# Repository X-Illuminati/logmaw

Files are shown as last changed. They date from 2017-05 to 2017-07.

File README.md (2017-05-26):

# logmaw
3D printable vice jaws to convert a "4 in." drill press vice into a makeshift stickvice for electronics workholding.

This is basically an exercise in learning OpenSCAD for me.

The part I've modeled is a set of vice jaws for a relatively generic 4 inch drill press vice.
In this case, I got the vice from [Harbor Freight](https://www.harborfreight.com/4-inch-jaw-capacity-drill-press-vise-30999.html).

In order to use the vice for electronics workholding (soldering, etc.), I have added a simple slot to the design.
Additionally, I have made most of the design parametric, which turned out to be useful since the screw-holes
in the existing vice jaws were clearly drilled with no regard for symmetric placement.

The main STL is [vice_jaws.stl](vice_jaws.stl), but anyone seeking to print these will
probably want to modify the .scad files to match their own vice.

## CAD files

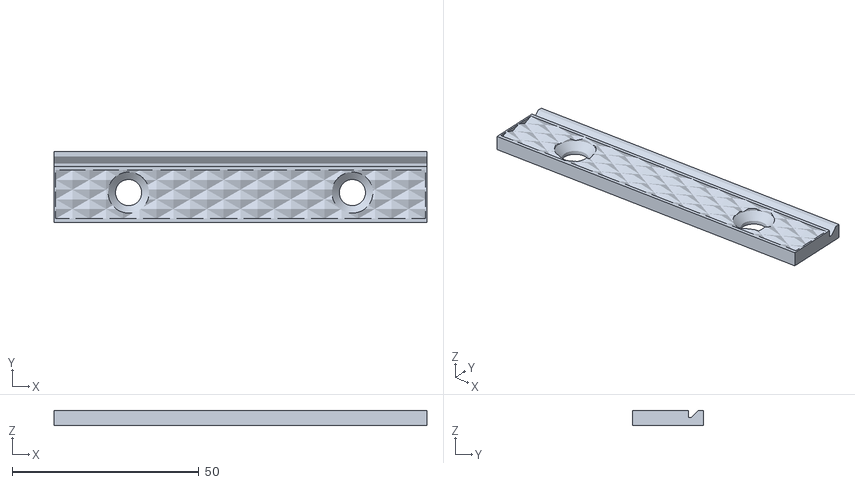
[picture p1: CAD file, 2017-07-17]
vice_jaws.stl
100.0 x 19.0 x 4.00

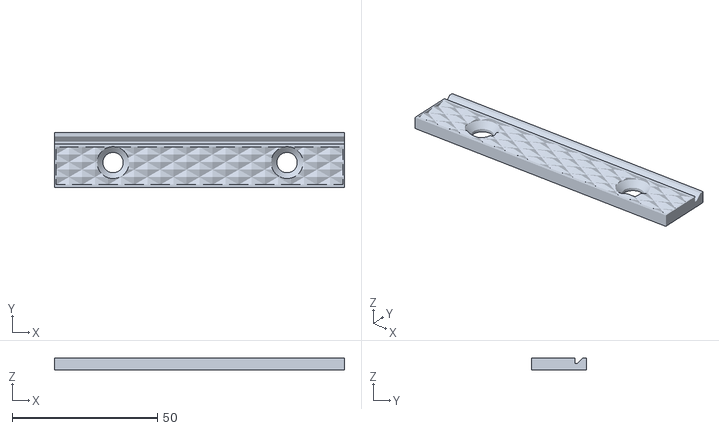
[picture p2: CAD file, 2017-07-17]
371291630_dynamic.stl
100.0 x 19.0 x 4.00

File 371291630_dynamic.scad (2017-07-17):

/*
 * includes
 */
include <vice_jaws.scad>

/*
 * custom settings for vice_jaws.scad
 */
generate_example=false;
bolt_x_offset=0.2;
bolt_y_offset=-0.9;
bolt_distance=60;

/*
 * global defines
 */
label_text1="371291630";
label_text2="dynamic jaw";
label_size=5.5;
label_depth=0.3;

/*
 * main construction geometry
 */
difference() {
	vice_jaw();
	translate([jaw_length/2,jaw_width/2,0])
		rotate([0,180,0])
			linear_extrude(height=(label_depth*2), center=true) {
				translate([0,jaw_width/5,0])
					text(text=label_text1, size=label_size,
						halign="center", valign="center",
						font="Liberation Mono:style=Regular");
				translate([0,-jaw_width/5,0])
					text(text=label_text2, size=label_size,
						halign="center", valign="center",
						font="Liberation Mono:style=Regular");
			}
}

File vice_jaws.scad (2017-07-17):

/*
 * includes
 */
use <knurl/knurled_surface.scad>

/*
 * global defines
 * dimensions represent mm
 */
$fa=2;
$fs=0.5;

/// grid plane in which to place the main
/// construction geometry
/// 0 = xy
/// 1 = xz
/// 2 = yz
global_geometry_plane=0;

/// grid quadrant in which to place the main
/// construction geometry
/// 0 = centered
global_geometry_quadrant=1;

// jaw: basic jaw slab
jaw_length=100;
jaw_width=19;
jaw_thickness=4;

// bolt: bolt hole carvout
bolt_radius=3.5;
bolt_x_offset=0;    /// x/y offsets account for bolt hole locations
bolt_y_offset=-1.5; /// being slightly out in manufacturing
bolt_sink=1;        // sink the bolt head deeper into the jaw
bolt_distance=60;   // distance between bolt centers
bolt_chamfer=2;     // 45° chamfer will be applied

// slot: slot/groove to be made in the jaw
slot_inner_width=0.8;    // slot width at deepest point
slot_chamfer_width=1.85; // extra width from chamfer
slot_depth=1.85;
slot_ratio=1.0;   // location of slot as a proportion of jaw
slot_y_offset=-4; // offset applied on top of slot_ratio

//knurl: knurl the face of the jaw
knurl_face=true;   // set to false to disable the knurl
// knurl up to the bottom of the slot
knurl_width=jaw_width*slot_ratio+slot_y_offset;
knurl_thickness=1; // depth of the knurl
knurl_angle=30;
knurl_y_shrink=1;  // amount to shrink the knurl back from the vertical edge
knurl_x_shrink=1;  // amount to shrink the knurl back from the horizontal edge
knurl_scale=2.5;   // amount to scale the knurling
// a more pleasing knurl can result by tweaking
// the above 2 params
knurl_scale=(knurl_width+knurl_y_shrink*-2)*cos(knurl_angle)/(10*sin(45-knurl_angle/2));
knurl_x_shrink=50-11*(knurl_width+knurl_y_shrink*-2)/(5*tan(45-knurl_angle/2));

/*
 * module and function definitions
 */
// bolt object composed of main cylinder, chamfer cone,
// and optional extra cylinder to sink the bolt down
module bolt(h,r) {
	translate([0,0,-1]) cylinder(h=h+1,r=r);
	translate([0,0,h-bolt_chamfer-bolt_sink])
		cylinder(h=bolt_chamfer,r1=r,r2=r+bolt_chamfer);
	translate([0,0,h-bolt_sink-.025])
		cylinder(h=bolt_sink+1,r=r+bolt_chamfer);
}

// return the center point between the two bolts
function bolt_center() =
	[
		jaw_length/2-bolt_distance/2+bolt_x_offset,
		jaw_width/2+bolt_y_offset,
		0
	];

// slot object which is narrow at the deepest part and then
// widens in a chamfer to a maximum as it reaches the surface
module slot(length) {
//	translate([-1,0,0])
//		cube([length+2, slot_inner_width, slot_depth+1]);
	translate([length+1,0,0])
		rotate([90,0,-90])
		linear_extrude(height=length+2)
			polygon([
				[0,-slot_depth],
				[slot_inner_width,-slot_depth],
				[slot_inner_width,1],
				[-slot_chamfer_width,1],
				[-slot_chamfer_width,0],
				[0,-slot_depth]		
			]);
};

// return the position of the slot (bottom of y)
function slot_position(ratio=0.5,offset=0) =
	[
		0,
		jaw_width*ratio+slot_inner_width+offset,
		jaw_thickness
	];

/// rotate the geometry globally
/// plane - the plane to use as the surface for
///         the main construction geometry
///         0 = xy
///         1 = xz
///         2 = yz
module global_rotate(plane=0) {
	if (plane == 1)
		rotate([90,0,0]) children();
	else if (plane == 2)
		rotate([90,0,90]) children();
	else
		children();
}

/// translate the geometry globally
/// quadrant - the grid quadrant to use as the
///         surface for the main construction
///         geometry
///         0 = center on origin
module global_translate(quadrant=1) {
	if (quadrant == 0)
		translate([-jaw_length/2,-jaw_width/2,0]) children();
	else if (quadrant == 2)
		translate([-jaw_length,0,0]) children();
	else if (quadrant == 3)
		translate([-jaw_length,-jaw_width,0]) children();
	else if (quadrant == 4)
		translate([0,-jaw_width,0]) children();
	else
		children();
}

// return the position of the knurl region
function knurl_position() =
	[
		knurl_x_shrink,
		knurl_y_shrink,
		jaw_thickness-knurl_thickness
	];

// return the dimensions for the knurl region
function knurl_dimension() =
	[
		jaw_length+knurl_x_shrink*-2,
		knurl_width+knurl_y_shrink*-2,
		knurl_thickness
	];

/*
 * main construction geometry
 */
module vice_jaw() {
	global_rotate(global_geometry_plane)
		global_translate(global_geometry_quadrant) {
			difference() {
				if (knurl_face)
					union() {
						difference() {
							cube([jaw_length, jaw_width, jaw_thickness]);
							translate(knurl_position())
									cube(knurl_dimension());
						}
						translate(knurl_position())
							knurled_surface(size=knurl_dimension(),
								scale=knurl_scale,
								angle=knurl_angle,
								thickness=knurl_thickness);
					}
				else
					cube([jaw_length, jaw_width, jaw_thickness]);
				translate(bolt_center()) {
					bolt(h=jaw_thickness, r=bolt_radius);
					translate([bolt_distance,0,0])
						bolt(h=jaw_thickness, r=bolt_radius);
				}
				translate(slot_position(ratio=slot_ratio,offset=slot_y_offset))
					slot(jaw_length);
			}
		}
}

/*
 * create example construction
 * add "generate_example=false;" to any files that include this one
 */
generate_example=true;
if (generate_example)
	vice_jaw();

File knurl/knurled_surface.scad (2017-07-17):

/*
 * knurled surface library
 *
 * use <knurled_surface.scad>
 * knurled_surface();
 */

// generate a "knurler" that covers at least the given size rectangle
// depth of the knurl will be controlled by size.z
// angle controlls the obliqueness of the diamond pattern
// the "knurler" creates a knurling pattern made of long, thin
// rectangular prisms that are rotated 45°
// these are arranged in a hash pattern at the given angle
module knurl(size=[10,10,1], angle=30)
{
	width=size.z*2;
	angle=(90-angle)/2;

	module hash(mirror=false)
	{
		disp=width/cos(angle);
		dy=size.x*tan(angle);
		cstart=mirror?floor(-dy/width-.5)-1:0;
		count=floor((size.y+dy)/width+.5)+1;
		cend=mirror?(count+cstart+1):count;
		for (yy=[cstart:1:cend])
			translate([0,yy*disp,0])
				mirror([0,mirror?1:0,0])
				rotate([45,0,-angle])
					translate([-width/2,0,0])
						cube([(size.x+width)/cos(angle),
							width/sqrt(2),
							width/sqrt(2)]);
	}

	union() {
		hash();
		hash(mirror=true);
	}
}

// create a rectangular knurled surface by subtracting a
// "knurler" from a cube
// the thickness of the cube is controlled by the thickness
// parameter rather than by size.z
module knurled_surface(size=[10,10,1], angle=30, thickness=2, scale=1)
{
	scale([scale,scale,1])
		difference() {
			cube([size.x/scale,size.y/scale,thickness]);
			translate([0,0,thickness-size.z])
				knurl([size.x/scale,size.y/scale,size.z], angle);
		}
}

// example knurled surface
knurled_surface(size=[35,15,1], angle=35, thickness=1.5, scale=2);

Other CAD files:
371291630_static.stl
371291630_static.scad

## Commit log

2017-05-26 basic parametric model
    [vice_jaws.scad, vice_jaws.stl]
2017-05-26 Add ability to locate geometry globally
    The geometry can now be translated to a specific
    grid plane and quadrant.
    The plane selected will serve as the flat surface
    from which the geometry is extruded.
    I.E. a 3D-printer print bed.
    The quadrant selected will translate the model into
    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
    [vice_jaws.scad]
2017-05-26 set some reasonable values based on measurements
    [vice_jaws.scad, vice_jaws.stl]
2017-05-26 create models for the 2 jaws in my vice
    static is the non-moving jaw
    dynamic is the moving jaw
    values for the bot offsets based on measurements
    [371291630_dynamic.scad, 371291630_dynamic.stl, 371291630_static.scad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]
2017-07-09 Include vice_jaws.scad in other scad docs
    The 'use' statement would probably be better, but I didn't
    really structure this right for that.
    Instead set 'generate_example' to 0 to avoid creating the
    example geometry.
    I think the change to the .stl files is unrelated.
    Just rendering with a newer version of CGAL, probably.
    [371291630_dynamic.scad, 371291630_dynamic.stl, 371291630_static.scad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]
2017-07-09 Add part labels
    [371291630_dynamic.scad, 371291630_dynamic.stl, 371291630_static.scad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]
2017-07-11 Tweak files based off initial print
    -Adjust bolt spacing and depth
    -Increase font size
    [371291630_dynamic.scad, 371291630_dynamic.stl, 371291630_static.scad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]
2017-07-13 knurl: Add scale support
    [knurled_surface.scad]
2017-07-13 knurl: make knurling direction more predictable
    [knurled_surface.scad]
2017-07-13 Increase the knurling scale
    [371291630_dynamic.stl, 371291630_static.stl, vice_jaws.scad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]
2017-07-13 Tweak files based off second print
    -Move text to back side
    -Adjust bolt spacing slightly
    (turns out I moved them the wrong direction the first time)
    [371291630_dynamic.scad, 371291630_dynamic.stl, 371291630_static.scad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]
2017-07-17 Revert "knurl: make knurling direction more predictable"
    This reverts commit 7f681bcfb5e18ab87d32eb6255806d9c5da95ce8.
    [knurled_surface.scad]
2017-07-17 knurl: simplify and balance the hash block around the x-axis
    [knurled_surface.scad]
2017-07-17 Refresh models after updating knurl lib
    [371291630_dynamic.stl, 371291630_static.stl, vice_jaws.scad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]
2017-07-17 Tweak files based off third print
    [371291630_dynamic.scad, 371291630_dynamic.stl, 371291630_static.scad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]
